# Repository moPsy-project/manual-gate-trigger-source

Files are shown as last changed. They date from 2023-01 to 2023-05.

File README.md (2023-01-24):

# Manual Gate/Trigger Source

> Eurorack Module for a manual gate/trigger source

## Dependencies

This project uses symbols from the [moPsy-KiCad-resources](https://github.com/moPsy-project/moPsy-KiCad-resources).

## License



This work is licensed under a [Creative Commons Attribution-ShareAlike 4.0 International License](http://creativecommons.org/licenses/by-sa/4.0/).

BY: Stefan Haun (mail@tuxathome.de)

See [LICENSE.txt](LICENSE.txt) for details.

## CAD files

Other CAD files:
Frontpanel/manual-gate-outline.FCStd
Frontpanel/manual-gate-outline.dxf

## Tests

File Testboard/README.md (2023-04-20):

# Testboard

> Testboard for the Eurorack Module for a manual gate/trigger source

As described in #53, buttons do not always trigger reliably after a cold start,
i.e. a longer period without power.

This happens on all buttons, but only in the finished circuit. The effect could not be observed on the breadboard and is therefore hard to debug.

This board contains only one trigger and some testpoints.

It is meant to be connected to the [Eurorack Power Breakout](https://github.com/moPsy-project/eurorack-power-breakout).

## Dependencies

This project uses symbols from the [moPsy-KiCad-resources](https://github.com/moPsy-project/moPsy-KiCad-resources).

## License



This work is licensed under a [Creative Commons Attribution-ShareAlike 4.0 International License](http://creativecommons.org/licenses/by-sa/4.0/).

BY: Stefan Haun (mail@tuxathome.de)

See [LICENSE.txt](LICENSE.txt) for details.

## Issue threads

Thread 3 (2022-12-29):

:white_check_mark: Verify stability of op-amp circuits

penguineer, 2022-12-29:
Verify transient behavior with an oscilloscope, at least on the breadboard.

See also https://www.jensen-transformers.com/wp-content/uploads/2014/08/an001.pdf

penguineer, 2023-01-10:
## Setup

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

Simple setup of an TL072 as buffer (unity gain amplifier) and a switch with high pass filter for full voltage swing in a short amount of time.

## Measurement

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

No ringing or resonance could be observed.

Closed 2023-01-10.

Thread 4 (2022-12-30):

:art: Consider alternative voltage generator design

penguineer, 2022-12-30:
The current design using series voltage dividers requires a 3-position selector (SP3T) switch.

Is there a way to implement the resistor divider for voltage generation by using a SPDT switch?
(Such as adding resistors in parallel to shift the voltage.)

(-12V are available, so it might be possible to move 8V to 5V and 10V to honour switch position and natural number order for the voltages.)

This decision can also be influenced by parts availability regarding the switch (#6).

Closed 2023-01-11.

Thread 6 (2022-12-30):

:wrench: Voltage switch selection and footprint

penguineer, 2022-12-30:
Select the appropriate voltage switch (also consider #4) and add the matching footprint.

penguineer, 2023-01-11:
We have decided for an SPDT switch with middle off position (ON/OFF/ON), that can also be replaced by jumper settings.

penguineer, 2023-01-26:
Alternatively this could be a small switch like [SS X23200](http://www.reichelt.de/index.html?ARTICLE=105437) - Schiebeschalter 2x Ein - Ein - Ein

penguineer, 2023-03-09:
When doing Concept 4 of the front panel design, I decided to stick with the decision for a voltage switch.

Closed 2023-03-09.

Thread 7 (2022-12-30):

:wrench: Choose gate length design

penguineer, 2022-12-30:
There are currently two design options for the gate length generator in the schematic:
* LM555 timer
* TL072 op-amp

The op-amp design is untested, but needs fewer components and has the right polarity for the rest of the build (output polarity can be switched easily).

- [x] Test the op-amp design on a breadboard → does not work as desired
- ~~If it works:~~
  - ~~remove 555 design~~
  - ~~change polarity of output~~
- if it does not work:
  - [x]  remove op-amp design
  - ~~change polarity of input~~

penguineer, 2023-01-09:
As discussed in https://github.com/moPsy-project/manual-gate-trigger-source/issues/9#issuecomment-1376312371 the op-amp circuit does not work as desired.

Closed 2023-01-10.

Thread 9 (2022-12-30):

:white_check_mark: Breadboard Experiments

penguineer, 2022-12-30:
Go to the lab (aka [Netz39 Hackerspace](https://www.netz39.de)) and do the following experiments:

- [x] Verify the gate/trigger input is working as intended → https://github.com/moPsy-project/manual-gate-trigger-source/issues/9#issuecomment-1379484607
  - [x] Verify the manual trigger has no bounce effects
  - [x] Verify the gate switch is working as intended
  - [x] Check the signal polarity on the trigger input
  - [x] Check if LPF is needed
  - [x] Fix manual switch circuit → https://github.com/moPsy-project/manual-gate-trigger-source/pull/18
- [x] Verify the op-amp gate length generator → https://github.com/moPsy-project/manual-gate-trigger-source/issues/9#issuecomment-1376312371
  - [x] Verify the circuit is working as intended
  - [x] Check the signal polarity
  - ~~Check if circuit timing is accurate under trigger output load~~
- [x] Verify the 555 gate length generator → https://github.com/moPsy-project/manual-gate-trigger-source/issues/9#issuecomment-1377659194
  - [x] Verify the circuit is working as intended
  - [x] Check the signal polarity
  - [x] Tune the RC values
- [x] Verify the voltage source → https://github.com/moPsy-project/manual-gate-trigger-source/issues/9#issuecomment-1378058845
  - [x] Verify the voltages can be generated and adjusted easily
  - [x] Check output behavior when switching voltages
  - [x] Verify circuit is stable under load
  - [x] Check if LPF is needed
  - [x] Check if feedback capacitor is needed
- [x] Verify gate/trigger output → https://github.com/moPsy-project/manual-gate-trigger-source/issues/9#issuecomment-1379542623
  - [x] Check polarity and verify it matches
  - [x] Verify step behaviour
  - [x] Verify that voltages are output correctly
  - [x] Investigate behavior with changing collector voltages
  - [x] Verify the push-pull behaviour
- ~~Verify transient behavior for power supply filter~~ → Go with the Befaco-inspired design for now. PSU filtering is a bigger topic for another (soon) time.

penguineer, 2023-01-09:
# Verify the op-amp gate length generator

## Setup
The op-amp based pulse generator has been set up on a breadboard with one modification: The timing capacity is set against V- instead if GND to observe polarity, as an electrolytic capacitor was used.

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

It could be verified that the circuit behaves as described.

## Polarity

The specific TL072 used in this experiment could swing up to 1V towards the rails, so the upper output was kept at 11V towards V+ and the lower output was kept at -11V towards V-.

In it's stable state the circuit outputs V+. If the input goes sufficiently below 0V/GND, the output swings towards V- until the set time has run out, then swings back to +V.

In this sense it has a negative polarity.

## Measurement

The circuit has been measured with its output at channel 1 (yellow) and the timing capacitor at channel 2 (cyan).
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

 Overall the behaviour is as expected. Timing is accurate.

Two negative observations:
* There is a slight ringing in the edges (only slightly visible in the shown measurement), which may be due to the fact that this op-amp is not ideal in a comperator setting.
* While the edge is triggered, the output is slightly below its stable value. While this would be compensated by the output circuit, it is not ideal.

It has also been observed that the trigger reacts to the rising edge, i.e. the end of the trigger pulse and is kept at stable level until that pulse has ended.

## Conclusion

While the circuit behaves as described, it's re-trigger behaviour makes it not suitable for the use case.

Since this variant will not be chosen, the accuracy under load has not been measured.

penguineer, 2023-01-10:
# Verify the 555 gate length generator

## Setup

The 555 based generator has been set up on  a breadboard as is.
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

## Polarity and behavior

The monoflop triggers on a falling edge (V+ → GND) and outputs a rising pulse (GND → V+ → GND).
If the trigger is held, the output stays at V+ until the trigger is released or the pulse times out, whichever comes _last_.

## Measurement
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

The output signal (channel 1, yellow) behaves as expected.
Channel 2 (cyan) shows the timing capacitor.

## Conclusion

The circuit is usable with changes to the RC element:
* Change capacitor to 2u2
* Change series resistor to 2k2

penguineer, 2023-01-11:
# Verify the voltage source

## Voltage selection

Voltage selection has been verified in a spice simulation. All voltages could be selected within 80% of the potentiometer range.

penguineer, 2023-01-11:
# Verify the gate/trigger input is working as intended

## Switching Behaviour

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

The leading edge is very sharp and sufficient for our application.

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

The trailing edge is rather slow. However, the change is finished in 50us, which is much shorter than the 1ms minimal gate length.

## Polarity

After a correction in the schematic the input has the desired inverting polarity.

## Conclusion

The circuit works as intended and has the desired switching behaviour.

penguineer, 2023-01-11:
# Verify gate/trigger output

## Setup

The adapted circuit from https://github.com/moPsy-project/manual-gate-trigger-source/pull/16 has been set up on a breadboard:
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

## Switching behavior
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

Switching is sufficiently fast.

Please note that these measurements have been done with BC337/BC227 replacements.

## Conclusion

The push-pull setup is usable.

penguineer, 2023-01-17:
# Final output signal

## Raising edge
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

## Falling edge
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

## Shortest trigger pulse
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

penguineer, 2023-01-17:
#Final Breadboard setup

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

Closed 2023-01-17.

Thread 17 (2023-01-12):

:wrench: Potentiometer selection and footprint

penguineer, 2023-01-12:
Select a fitting potentiometer (1M linear) and find/create a footprint.

penguineer, 2023-01-19:
The following potentiometer has been selected: [Potentiometer - 12mm B1M x5 units](https://shop.befaco.org/potentiometers/279-5x-potentiometer-1m.html)

> 12mm potentiometer with T-18 Knurled shaft. These potentiomters have a 1MΩ linear taper.

Reference: `POTB1M`

Closed 2023-01-25.

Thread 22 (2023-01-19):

:wrench: Gate/Trigger switch selection and footprint

penguineer, 2023-01-19:
Select the appropriate gate/trigger switch and add the matching footprint.

penguineer, 2023-01-19:
Proposition: [Toggle Mini Switch - SPDT ON-ON x5 units](https://shop.befaco.org/switches/265-toggle-mini-switch-spdt-on-on-x5-units.html)

> Miniature SPDT on-on toggle switches with pins for PCB mounting.

References:
* `TSM102A2`
* `SW1`

penguineer, 2023-01-19:
This could also be a push switch to save some space.

penguineer, 2023-01-25:
Another Option: [T 113A BL](http://www.reichelt.de/index.html?ARTICLE=45163) - Miniatur-Drucktaster 0,5A-24VAC, 1x (Ein), bl

As a push-button with state and an indicator LED this might be a better solution.

penguineer, 2023-01-26:
https://www.henrik24.de/de_DE/p/Mikro-Druckschalter-7x7mm-6-Pin-Rastend-Typ/274

Closed 2023-03-08.

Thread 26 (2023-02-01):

:hammer: Redesign voltages for +3V/+5V/+12V

penguineer, 2023-02-01:
According to https://doepfer.de/a100_man/a100t_e.htm, gate voltages should be above 3V, are 5V default and need to be tolerated as 12V.

These should be the voltages we support, which means that #21 is an option for a better voltage supply.

Closed 2023-03-12.

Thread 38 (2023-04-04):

ready to rock?

KeLaiFu, 2023-04-04:
I've been watching you work on this project with great interest and noticed you seem to have stopped the regular updates, does this mean the circuit has reached its final form? I have been toying with the same idea, with less success so I am interested in using your schematic as the base of my euro module.

Really appreciate the stuff you're uploading. thanks!

penguineer, 2023-04-04:
Thank you very much for your nice feedback! :smiley:
You are right, the recent steps in this project didn't leave much of a trace here.

The state of the project:
[The first prototype is done and works.](https://www.patreon.com/posts/first-module-is-80765545) However, while building, I discovered some minor issues with the PCB that need to be worked out.
The circuit itself seems to be working.

So there will be a v1.1 with bugfixes on the PCB.

I am also thinking about a v2 where I drop the voltage switch. This came from a testing environment, but I might solve it differently there and in the performance setup I don't really see as much use for this feature (at least in relation to the effort I made in development and parts to implement this).

penguineer, 2023-04-04:
I am happy to sell you a prototype of v1 for a fair price (covering material and shipping costs), in case you are interested.
As I haven't created build instructions yet, assembling a kit might be a bit of a chore, especially with the current kinks.

Please feel free to get inspiration for your own builds or point out mistakes in my design, :)

penguineer, 2023-04-04:
I am closing this issue and will create new issues with my findings to make it easier to follow up on the progress.

Closed 2023-04-04.

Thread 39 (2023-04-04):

:bug: Fix cutout dimensions in the front panel

penguineer, 2023-04-04:
The front panel cutouts are a bit too tight:
* [x] Height of the cherry switches
* [x] Diameter for the potentiometers

* [x] Diameter for the diodes could also be increased, but works well this way, too.

penguineer, 2023-04-04:
>  Diameter for the potentiometers

After measuring the PCBs: The diameter is correct. It turns out that the cutouts by JLCPCB are smaller than specified.

Closed 2023-04-04.

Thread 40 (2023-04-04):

:bug: Cosmetic issues with v1

penguineer, 2023-04-04:
There are some cosmetic issues with v1:
* [x] The front panel has no solder mask
* [x] URI on the interface panel is mirrored
* [x] Adjustment pots do not state their voltage range

penguineer, 2023-04-04:
> The front panel has no solder mask

This looks interesting, too.

However, I want to figure out
* why the solder mask is missing
* if partial solder mask can be used to improve design and readability

penguineer, 2023-04-04:
>  Adjustment pots do not state their voltage range

I intentionally did not put specific values, as they may be changed by choosing different resistors. But I still want to label with something along the line of "low", "mid", "high".

Closed 2023-04-04.

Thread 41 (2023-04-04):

:bug: High voltage range is too low

penguineer, 2023-04-04:
The pot for the high voltage range barely reaches the target on its upper limit. Resistor values need to be adjusted accordingly.

Closed 2023-05-19.

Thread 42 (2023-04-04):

:bug: 1M potentiometer footprints do not fit

penguineer, 2023-04-04:
After https://github.com/moPsy-project/moPsy-KiCad-resources/issues/13 fix the 1M pot footprints.

Closed 2023-04-04.

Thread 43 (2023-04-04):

:bug: Check the gate switch footprints

penguineer, 2023-04-04:
The gate switch footprints match the [drawing](https://www.henrik24.de/de_DE/p/Mikro-Druckschalter-7x7mm-6-Pin-Rastend-Typ/274#galleryName=productGallery,imageNumber=3), but not the switches which I used during assembly.

Check if there are indeed to varieties of these switches and fix accordingly, either the footprint or the switches.

Closed 2023-05-20.

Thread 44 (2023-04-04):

:lipstick: Replace voltage switch by (trim) potentiometer

penguineer, 2023-04-04:
The voltage switch is overkill in terms of effort (parts and space) to added value.

I want to replace this switch by a (trim) pot that allows to set the trigger output voltage between 4V and 9V (which includes the viable targets of 5V/8V).

This pot can be either on the back or even stick to the front (which has been done with trim pots e.g. in the [Erica Synths Black VCO](https://www.modulargrid.net/e/erica-synths-black-vco)).

penguineer, 2023-05-19:
It is possible to replace the switch while still using the existing frontpanel. Only disadvantage is that the hole is too big.

penguineer, 2023-05-19:
This issue has been fixed in https://github.com/moPsy-project/manual-gate-trigger-source/pull/57/commits/0d254281400b6e1f035b64f6f6d54457fdb192a0

Closed 2023-05-19.

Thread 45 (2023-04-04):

:art: Use 556 instead of 555 to save board space

penguineer, 2023-04-04:
There are four 555 ICs in this build. They can be replaced by two 556 ICs to save on board space and some capacitors.

This requires a review of the sheet hierarchy, tho.

penguineer, 2023-05-19:
This is no longer needed.

Closed 2023-05-19.

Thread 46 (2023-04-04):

:art: Get rid of the Power Board PCB

penguineer, 2023-04-04:
Find a better arrangement of parts to get rid of the additional Power Board PCB.

This will improve the assembly and decrease costs and failure modes.

If possible, this change should be part of [v1.1](https://github.com/moPsy-project/manual-gate-trigger-source/milestone/3https://github.com/moPsy-project/manual-gate-trigger-source/milestone/3), however, if this is not possible, #44 and #45 have to be be resolved first.

Closed 2023-05-19.

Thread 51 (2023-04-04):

:bug: Voltage switch is too high on the board

penguineer, 2023-04-04:
The voltage switch is too high, pushing the front plate 1mm out of alignment.

This can be fixed by creating a footprint that allows the pins to go all the way in, effectively making the switch body sit flat on the PCB.

Closed 2023-04-12.

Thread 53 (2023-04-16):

:bug: Buttons do not always trigger reliably

penguineer, 2023-04-16:
After turning the module on (i.e. switching power on) it sometimes takes a few button pushes to make the buttons trigger reliably. As this is the core function of the module, the behavior is not satisfactory and needs to be improved.

~~The hardware debouncing may be too harsh and is most likely not even used, as the 555 timers make sure that there is a mimimal signal length.~~

penguineer, 2023-04-19:
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

This capacitor is not needed, as the 555 catches any bouncing from the button.

penguineer, 2023-04-21:
Follow-up measurements will be done on a testboard:

[testboard-gerber.zip](https://github.com/moPsy-project/manual-gate-trigger-source/files/11294313/testboard-gerber.zip)

penguineer, 2023-05-17:
The test board has a reliable switch behavior, which makes me think that the actual V_drive generator is the issue.

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

This might be solved with #44 and #46.

penguineer, 2023-05-19:
Closing as I strongly suspect a fix in #57

Closed 2023-05-19.

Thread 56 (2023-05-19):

:art: Change transistor footprints for easier soldering

penguineer, 2023-05-19:
Switch to the TO-92 hand-soldering footprints, as the inline footprints tend to lead to solder bridges.

Closed 2023-05-20.

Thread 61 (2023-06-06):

:bug: Triggering is still unreliable

penguineer, 2023-06-06:
With the changes for v2 and even after the testboard triggering is still unreliable, yet in a more systematic way: The top buttons are less reliable than the bottom ones,leading me to believe that this is a power supply issue.

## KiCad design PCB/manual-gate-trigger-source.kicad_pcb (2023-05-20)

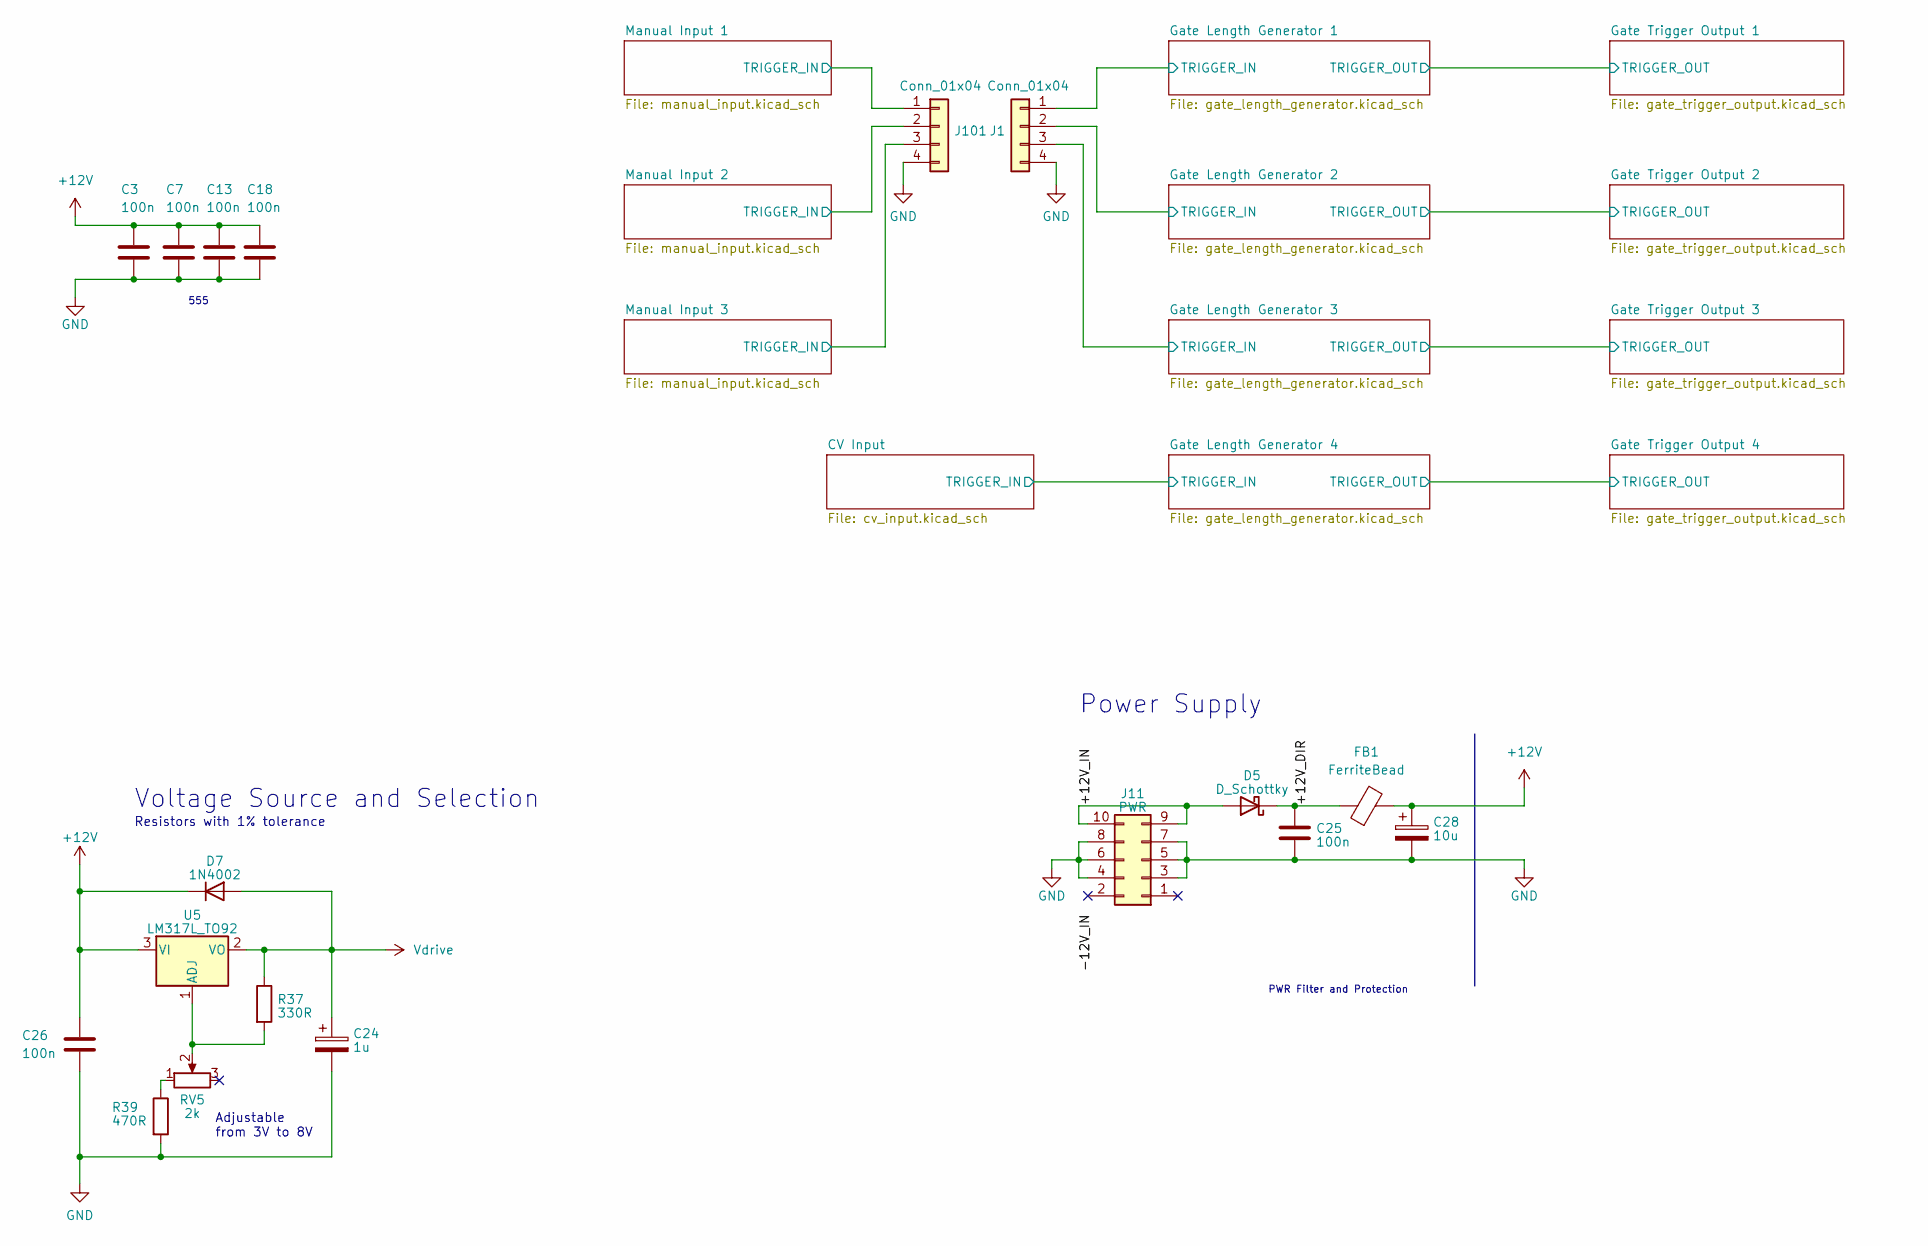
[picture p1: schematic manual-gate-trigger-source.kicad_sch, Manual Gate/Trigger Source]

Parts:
C3, C7, C13, C18, C25, C26: 100n; C_Disc_D4.3mm_W1.9mm_P5.00mm
C24: 1u; CP_Radial_D5.0mm_P2.00mm
C28: 10u; CP_Radial_D4.0mm_P1.50mm
D5: D_Schottky; D_DO-41_SOD81_P7.62mm_Horizontal
D7: 1N4002; D_DO-41_SOD81_P10.16mm_Horizontal
FB1: FerriteBead; FBeadL4D4
J1: Conn_01x04; PinSocket_1x04_P2.54mm_Vertical
J11: PWR; PinHeader_2x05_P2.54mm_Vertical
J101: Conn_01x04; PinHeader_1x04_P2.54mm_Vertical
R37: 330R; R_Axial_DIN0207_L6.3mm_D2.5mm_P7.62mm_Horizontal
R39: 470R; R_Axial_DIN0207_L6.3mm_D2.5mm_P7.62mm_Horizontal
RV5: 2k; Suntan 3296 Trim Pot
U5: LM317L_TO92; TO-92_HandSolder

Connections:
+12V: C3.1, C7.1, C13.1, C18.1, C26.1, C28.1, D7.1 (K), FB1.2, U5.3 (VI); also elsewhere on the board
/+12V_DIR: C25.1, D5.1 (K), FB1.1
/+12V_IN: D5.2 (A), J11.9, J11.10
/Gate Length Generator 1/TRIGGER_IN: J1.1; also elsewhere on the board
/Gate Length Generator 2/TRIGGER_IN: J1.2; also elsewhere on the board
/Gate Length Generator 3/TRIGGER_IN: J1.3; also elsewhere on the board
/Manual Input 1/TRIGGER_IN: J101.1; also elsewhere on the board
/Manual Input 2/TRIGGER_IN: J101.2; also elsewhere on the board
/Manual Input 3/TRIGGER_IN: J101.3; also elsewhere on the board
GND: C3.2, C7.2, C13.2, C18.2, C24.2, C25.2, C26.2, C28.2, J1.4, J11.3, J11.4, J11.5, J11.6, J11.7, J11.8, J101.4, R39.2; also elsewhere on the board
unnamed: R39.1, RV5.1
unnamed: R37.2, RV5.2, U5.1 (ADJ)
Vdrive: C24.1, D7.2 (A), R37.1, U5.2 (VO); also elsewhere on the board

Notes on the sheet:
PWR Filter and Protection
Resistors with 1% tolerance
555
Voltage Source and Selection
Power Supply
Adjustable from 3V to 8V

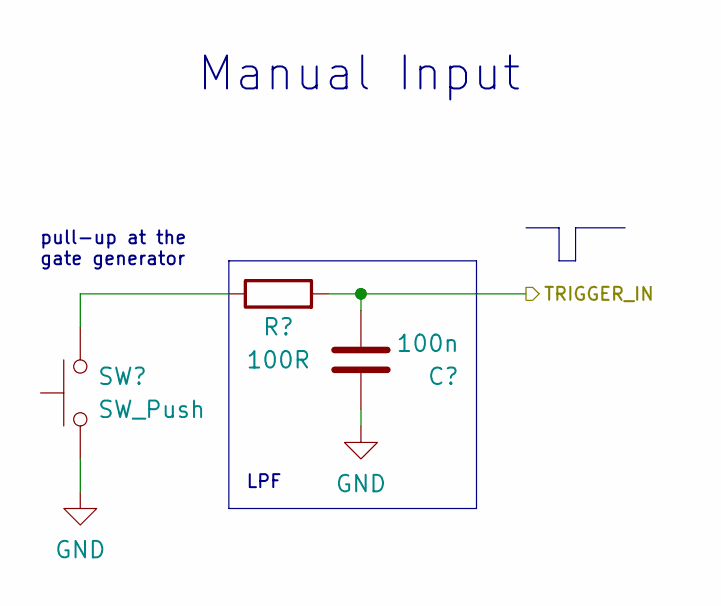
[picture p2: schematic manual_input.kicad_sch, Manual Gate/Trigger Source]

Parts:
C101: 100n; C_Disc_D4.3mm_W1.9mm_P5.00mm
R101: 100R; R_Axial_DIN0207_L6.3mm_D2.5mm_P7.62mm_Horizontal
SW101: SW_Push; SW_Cherry_MX_1.00u_PCB

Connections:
/Manual Input 1/TRIGGER_IN: C101.2, R101.2; also elsewhere on the board
GND: C101.1, SW101.1; also elsewhere on the board
unnamed: R101.1, SW101.2

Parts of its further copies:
C102, C103: 100n; C_Disc_D4.3mm_W1.9mm_P5.00mm
R102, R103: 100R; R_Axial_DIN0207_L6.3mm_D2.5mm_P7.62mm_Horizontal
SW102, SW103: SW_Push; SW_Cherry_MX_1.00u_PCB

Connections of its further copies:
/Manual Input 2/TRIGGER_IN: C102.2, R102.2; also elsewhere on the board
/Manual Input 3/TRIGGER_IN: C103.2, R103.2; also elsewhere on the board
GND: C102.1, C103.1, SW102.1, SW103.1; also elsewhere on the board
unnamed: R102.1, SW102.2
unnamed: R103.1, SW103.2

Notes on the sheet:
pull-up at the gate generator
LPF
Manual Input

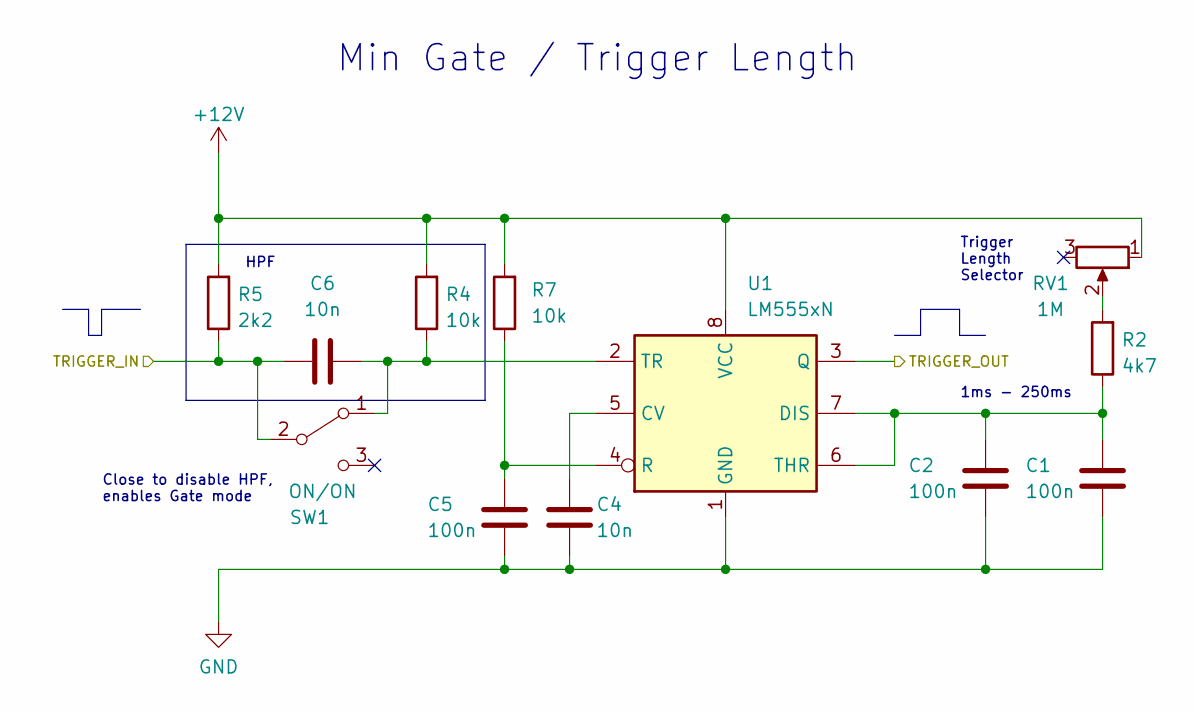
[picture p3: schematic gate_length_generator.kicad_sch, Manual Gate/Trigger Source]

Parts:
C1, C2, C5: 100n; C_Disc_D4.3mm_W1.9mm_P5.00mm
C4, C6: 10n; C_Disc_D4.3mm_W1.9mm_P5.00mm
R2: 4k7; R_Axial_DIN0207_L6.3mm_D2.5mm_P7.62mm_Horizontal
R4, R7: 10k; R_Axial_DIN0207_L6.3mm_D2.5mm_P7.62mm_Horizontal
R5: 2k2; R_Axial_DIN0207_L6.3mm_D2.5mm_P7.62mm_Horizontal
RV1: 1M; Potentiometer_Befaco_12mm_Single_Vertical
SW1: ON/ON; PB_Hor_7x7_2pole_hybrid
U1: LM555xN; DIP-8_W7.62mm

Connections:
+12V: R4.2, R5.2, R7.2, RV1.1, U1.8 (VCC); also elsewhere on the board
/Gate Length Generator 1/TRIGGER_IN: C6.1, R5.1, SW1.2 (B); also elsewhere on the board
/Gate Length Generator 1/TRIGGER_OUT: U1.3 (Q); also elsewhere on the board
GND: C1.2, C2.2, C4.2, C5.2, U1.1 (GND); also elsewhere on the board
unnamed: R2.2, RV1.2
unnamed: C6.2, R4.1, SW1.1 (A), U1.2 (TR)
unnamed: C4.1, U1.5 (CV)
unnamed: C1.1, C2.1, R2.1, U1.6 (THR), U1.7 (DIS)
unnamed: C5.1, R7.1, U1.4 (R)

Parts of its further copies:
C8, C9, C10, C14, C15, C16, C21, C22, C23: 100n; C_Disc_D4.3mm_W1.9mm_P5.00mm
C11, C12, C17, C19, C20, C27: 10n; C_Disc_D4.3mm_W1.9mm_P5.00mm
R10, R15, R25: 4k7; R_Axial_DIN0207_L6.3mm_D2.5mm_P7.62mm_Horizontal
R12, R17, R20, R24, R27, R35: 10k; R_Axial_DIN0207_L6.3mm_D2.5mm_P7.62mm_Horizontal
R18, R28, R36: 2k2; R_Axial_DIN0207_L6.3mm_D2.5mm_P7.62mm_Horizontal
RV2, RV3, RV4: 1M; Potentiometer_Befaco_12mm_Single_Vertical
SW2, SW3, SW4: ON/ON; PB_Hor_7x7_2pole_hybrid
U2, U3, U4: LM555xN; DIP-8_W7.62mm

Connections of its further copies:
+12V: R12.2, R17.2, R18.2, R20.2, R24.2, R27.2, R28.2, R35.2, R36.2, RV2.1, RV3.1, RV4.1, U2.8 (VCC), U3.8 (VCC), U4.8 (VCC); also elsewhere on the board
/CV Input/TRIGGER_IN: C27.1, R36.1, SW4.2 (B); also elsewhere on the board
/Gate Length Generator 2/TRIGGER_IN: C12.1, R18.1, SW2.2 (B); also elsewhere on the board
/Gate Length Generator 2/TRIGGER_OUT: U2.3 (Q); also elsewhere on the board
/Gate Length Generator 3/TRIGGER_IN: C20.1, R28.1, SW3.2 (B); also elsewhere on the board
/Gate Length Generator 3/TRIGGER_OUT: U3.3 (Q); also elsewhere on the board
/Gate Length Generator 4/TRIGGER_OUT: U4.3 (Q); also elsewhere on the board
GND: C8.2, C9.2, C10.2, C11.2, C14.2, C15.2, C16.2, C17.2, C19.2, C21.2, C22.2, C23.2, U2.1 (GND), U3.1 (GND), U4.1 (GND); also elsewhere on the board
unnamed: R10.2, RV2.2
unnamed: R15.2, RV3.2
unnamed: R25.2, RV4.2
unnamed: C12.2, R17.1, SW2.1 (A), U2.2 (TR)
unnamed: C20.2, R24.1, SW3.1 (A), U3.2 (TR)
unnamed: C27.2, R35.1, SW4.1 (A), U4.2 (TR)
unnamed: C11.1, U2.5 (CV)
unnamed: C8.1, C9.1, R10.1, U2.6 (THR), U2.7 (DIS)
unnamed: C10.1, R12.1, U2.4 (R)
unnamed: C17.1, U3.5 (CV)
unnamed: C14.1, C15.1, R15.1, U3.6 (THR), U3.7 (DIS)
unnamed: C16.1, R20.1, U3.4 (R)
unnamed: C19.1, U4.5 (CV)
unnamed: C21.1, C23.1, R25.1, U4.6 (THR), U4.7 (DIS)
unnamed: C22.1, R27.1, U4.4 (R)

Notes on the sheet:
Min Gate / Trigger Length
Trigger Length Selector
HPF
1ms - 250ms
Close to disable HPF, enables Gate mode

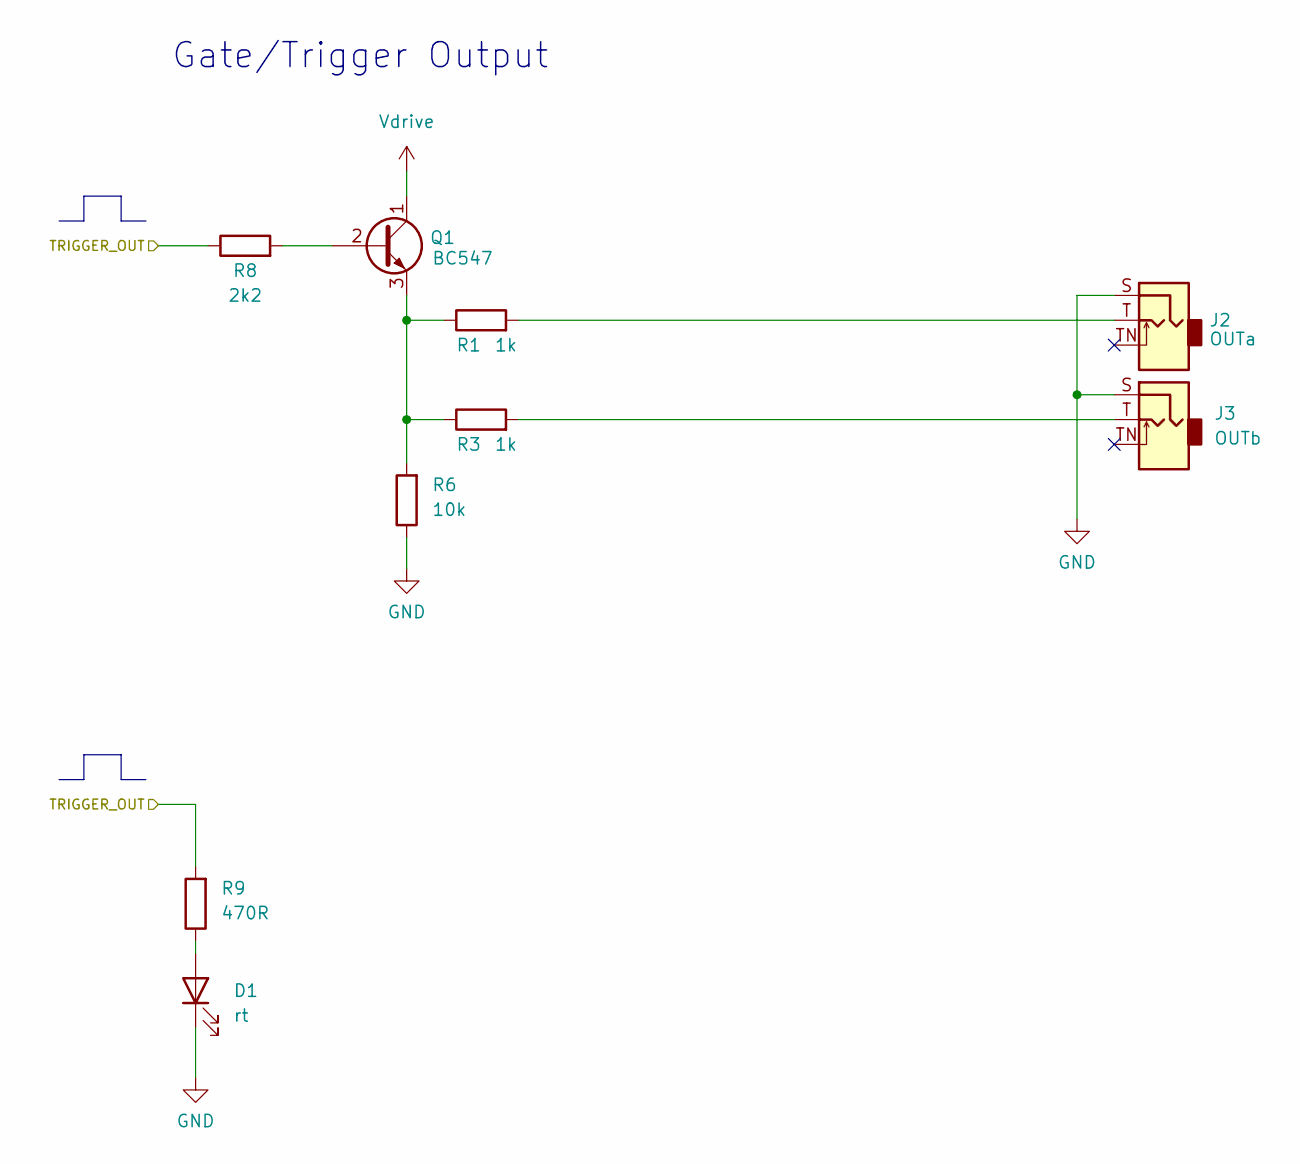
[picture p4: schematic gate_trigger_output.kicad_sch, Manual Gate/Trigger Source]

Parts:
D1: rt; LED_D3.0mm
J2: OUTa; Jack_3.5mm_QingPu_WQP-PJ398SM_Vertical_CircularHoles_Center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
J3: OUTb; Jack_3.5mm_QingPu_WQP-PJ398SM_Vertical_CircularHoles_Center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
Q1: BC547; TO-92_HandSolder
R1, R3: 1k; R_Axial_DIN0207_L6.3mm_D2.5mm_P7.62mm_Horizontal
R6: 10k; R_Axial_DIN0207_L6.3mm_D2.5mm_P7.62mm_Horizontal
R8: 2k2; R_Axial_DIN0207_L6.3mm_D2.5mm_P7.62mm_Horizontal
R9: 470R; R_Axial_DIN0207_L6.3mm_D2.5mm_P7.62mm_Horizontal

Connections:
/Gate Length Generator 1/TRIGGER_OUT: R8.1, R9.2; also elsewhere on the board
GND: D1.1 (K), J2.S, J3.S, R6.1; also elsewhere on the board
unnamed: D1.2 (A), R9.1
unnamed: J2.T, R1.2
unnamed: J3.T, R3.2
unnamed: Q1.2 (B), R8.2
unnamed: Q1.3 (E), R1.1, R3.1, R6.2
Vdrive: Q1.1 (C); also elsewhere on the board

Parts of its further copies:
D2, D3, D6: rt; LED_D3.0mm
J4, J6, J9: OUTa; Jack_3.5mm_QingPu_WQP-PJ398SM_Vertical_CircularHoles_Center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
J5, J7, J10: OUTb; Jack_3.5mm_QingPu_WQP-PJ398SM_Vertical_CircularHoles_Center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
Q2, Q3, Q4: BC547; TO-92_HandSolder
R11, R16, R21, R26, R33, R34: 1k; R_Axial_DIN0207_L6.3mm_D2.5mm_P7.62mm_Horizontal
R13, R23, R30: 2k2; R_Axial_DIN0207_L6.3mm_D2.5mm_P7.62mm_Horizontal
R14, R22, R29: 470R; R_Axial_DIN0207_L6.3mm_D2.5mm_P7.62mm_Horizontal
R19, R32, R38: 10k; R_Axial_DIN0207_L6.3mm_D2.5mm_P7.62mm_Horizontal

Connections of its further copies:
/Gate Length Generator 2/TRIGGER_OUT: R13.1, R14.2; also elsewhere on the board
/Gate Length Generator 3/TRIGGER_OUT: R22.2, R23.1; also elsewhere on the board
/Gate Length Generator 4/TRIGGER_OUT: R29.2, R30.1; also elsewhere on the board
GND: D2.1 (K), D3.1 (K), D6.1 (K), J4.S, J5.S, J6.S, J7.S, J9.S, J10.S, R19.1, R32.1, R38.1; also elsewhere on the board
unnamed: D2.2 (A), R14.1
unnamed: D3.2 (A), R22.1
unnamed: D6.2 (A), R29.1
unnamed: J4.T, R11.2
unnamed: J5.T, R16.2
unnamed: J6.T, R21.2
unnamed: J7.T, R26.2
unnamed: J9.T, R33.2
unnamed: J10.T, R34.2
unnamed: Q2.2 (B), R13.2
unnamed: Q2.3 (E), R11.1, R16.1, R19.2
unnamed: Q3.2 (B), R23.2
unnamed: Q3.3 (E), R21.1, R26.1, R32.2
unnamed: Q4.2 (B), R30.2
unnamed: Q4.3 (E), R33.1, R34.1, R38.2
Vdrive: Q2.1 (C), Q3.1 (C), Q4.1 (C); also elsewhere on the board

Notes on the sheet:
Gate/Trigger Output

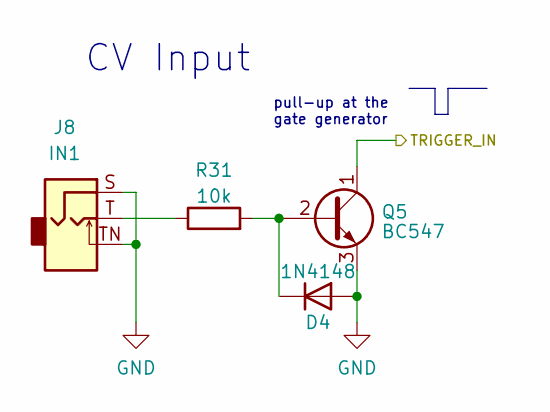
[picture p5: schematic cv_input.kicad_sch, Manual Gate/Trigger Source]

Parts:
D4: 1N4148; D_DO-35_SOD27_P7.62mm_Horizontal
J8: IN1; Jack_3.5mm_QingPu_WQP-PJ398SM_Vertical_CircularHoles_Center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
Q5: BC547; TO-92_HandSolder
R31: 10k; R_Axial_DIN0207_L6.3mm_D2.5mm_P7.62mm_Horizontal

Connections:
/CV Input/TRIGGER_IN: Q5.1 (C); also elsewhere on the board
GND: D4.2 (A), J8.S, J8.TN, Q5.3 (E); also elsewhere on the board
unnamed: D4.1 (K), Q5.2 (B), R31.2
unnamed: J8.T, R31.1

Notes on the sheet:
CV Input
pull-up at the gate generator

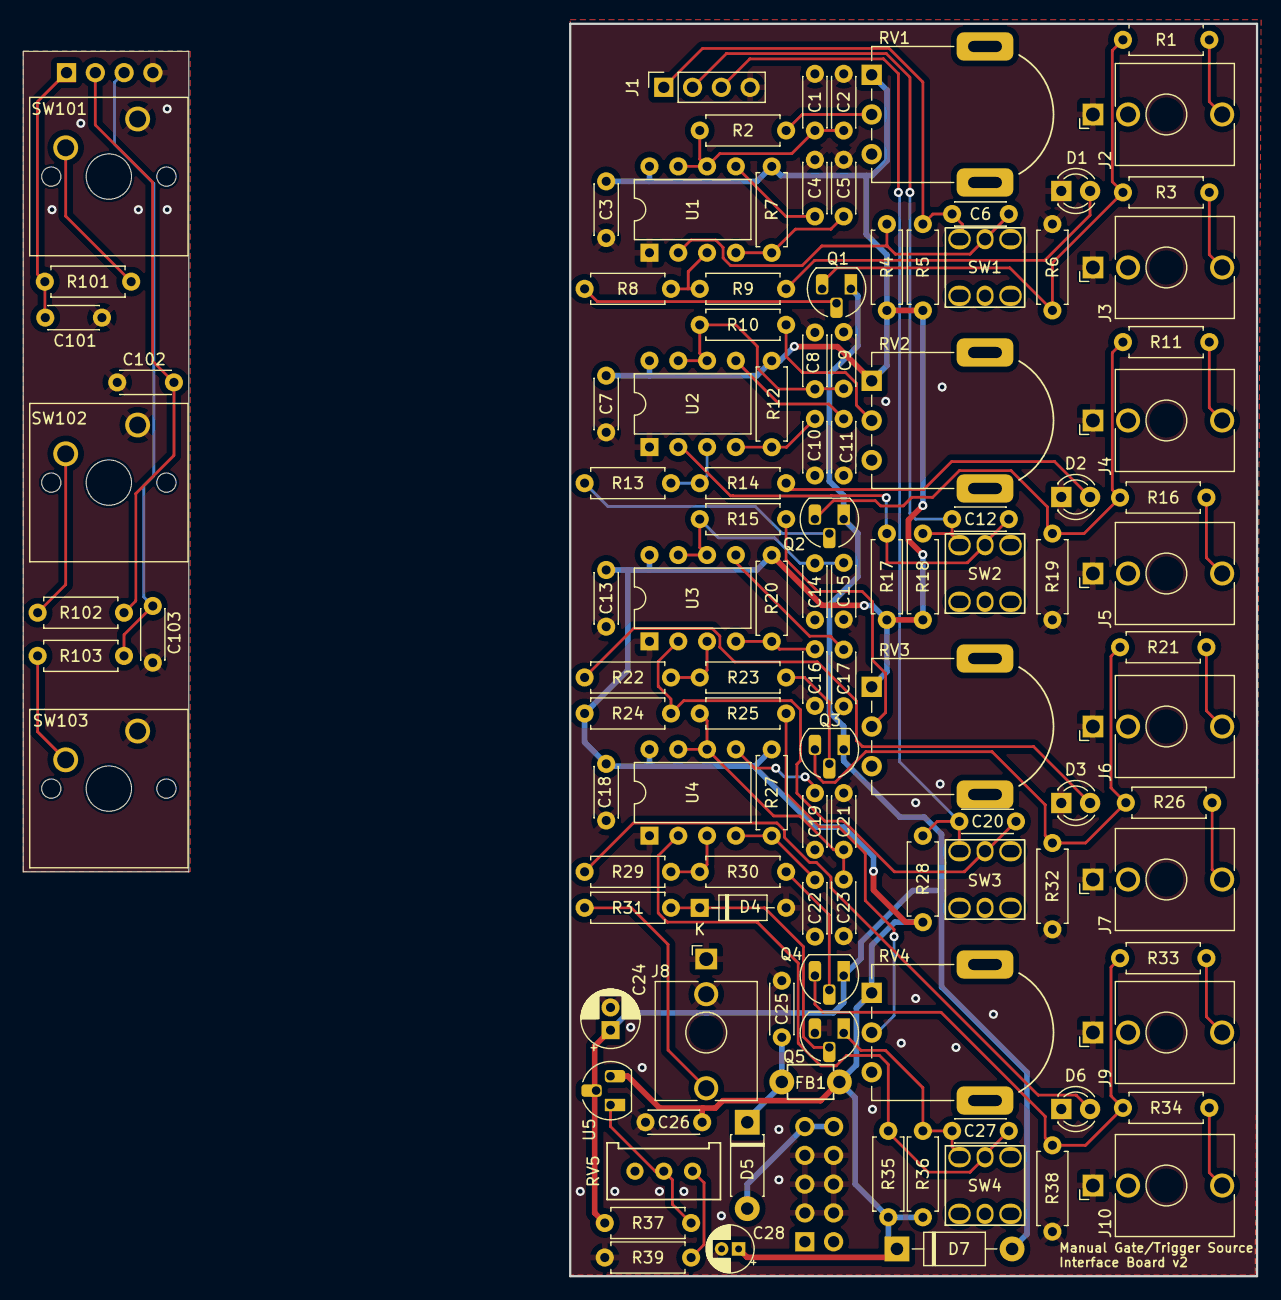
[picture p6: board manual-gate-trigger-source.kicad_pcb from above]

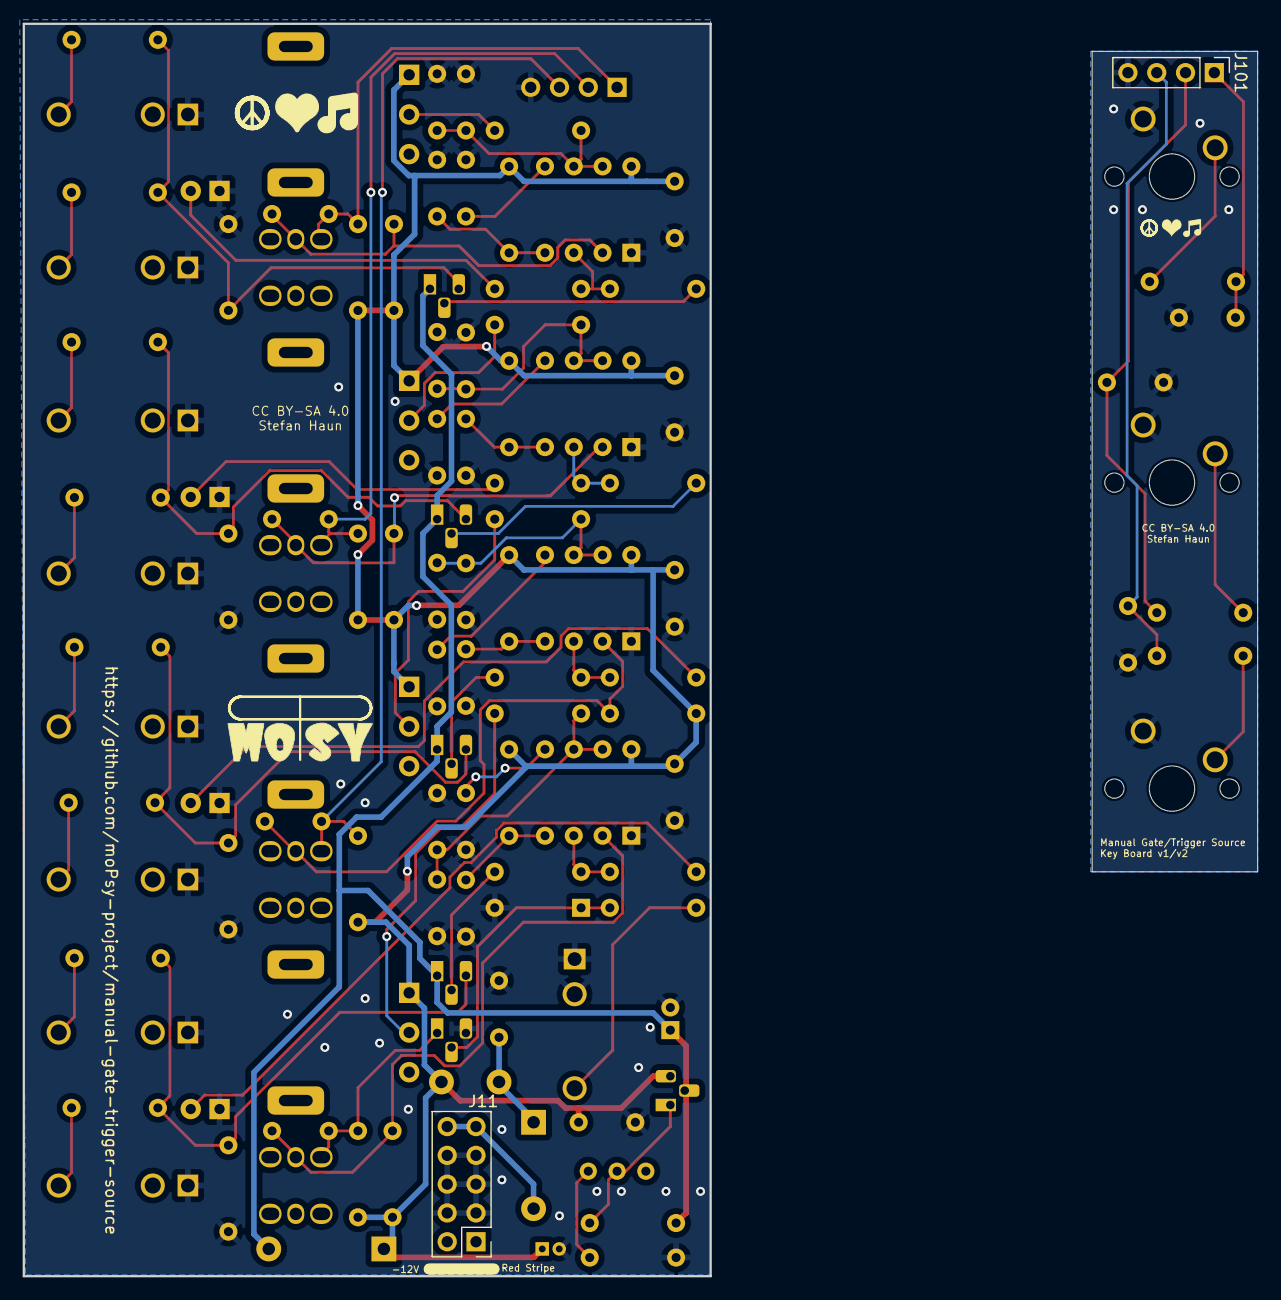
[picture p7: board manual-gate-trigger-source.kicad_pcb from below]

Board: 2 copper layers, 60.6 x 110.5 mm, 115 parts (2 on the bottom side), 63 nets.

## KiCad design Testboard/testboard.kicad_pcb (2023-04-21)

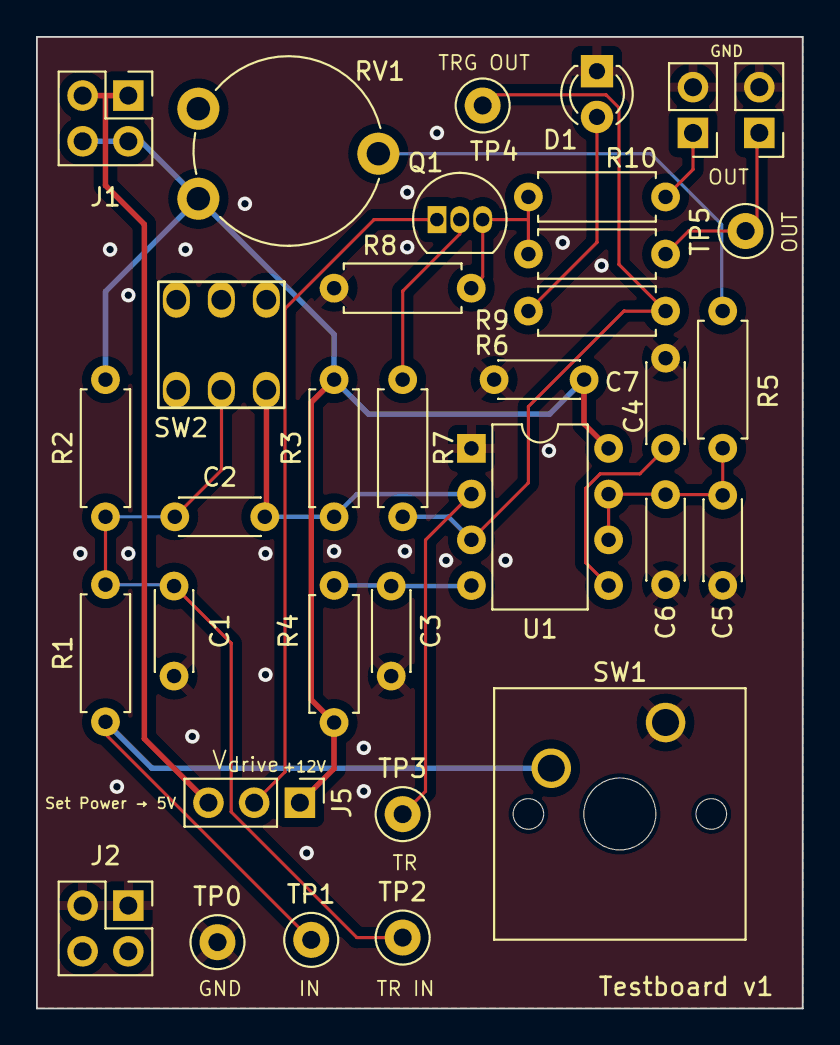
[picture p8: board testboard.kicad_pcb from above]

Board: 2 copper layers, 42.5 x 54.0 mm, 34 parts (0 on the bottom side), 17 nets.

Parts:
C1, C3, C5, C6, C7: 100n; C_Disc_D4.3mm_W1.9mm_P5.00mm
C2, C4: 10n; C_Disc_D4.3mm_W1.9mm_P5.00mm
D1: rt; LED_D3.0mm
J1: upper; PinSocket_2x02_P2.54mm_Vertical
J2: lower; PinSocket_2x02_P2.54mm_Vertical
J3, J4: Out; PinHeader_1x02_P2.54mm_Vertical
J5: V_{drive}; PinHeader_1x03_P2.54mm_Vertical
Q1: BC547; TO-92_Inline
R1: 100R; R_Axial_DIN0207_L6.3mm_D2.5mm_P7.62mm_Horizontal
R2, R7: 2k2; R_Axial_DIN0207_L6.3mm_D2.5mm_P7.62mm_Horizontal
R3, R4, R8: 10k; R_Axial_DIN0207_L6.3mm_D2.5mm_P7.62mm_Horizontal
R5: 4k7; R_Axial_DIN0207_L6.3mm_D2.5mm_P7.62mm_Horizontal
R6: 470R; R_Axial_DIN0207_L6.3mm_D2.5mm_P7.62mm_Horizontal
R9, R10: 1k; R_Axial_DIN0207_L6.3mm_D2.5mm_P7.62mm_Horizontal
RV1: 1M; Potentiometer_Piher_PT-10-V10_Vertical
SW1: SW_Push; SW_Cherry_MX_1.00u_PCB
SW2: ON/ON; PB_Hor_7x7_2pole_2.5mm
TP0: GND; TestPoint_Loop_D1.80mm_Drill1.0mm_Beaded
TP1: IN; TestPoint_Loop_D1.80mm_Drill1.0mm_Beaded
TP2: TRIGGER_IN; TestPoint_Loop_D1.80mm_Drill1.0mm_Beaded
TP3: TR; TestPoint_Loop_D1.80mm_Drill1.0mm_Beaded
TP4: TRIGGER_OUT; TestPoint_Loop_D1.80mm_Drill1.0mm_Beaded
TP5: OUT; TestPoint_Loop_D1.80mm_Drill1.0mm_Beaded
U1: LM555xN; DIP-8_W7.62mm

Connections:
+12V: C7.1, J1.3, J1.4, J5.1, R2.2, R3.2, R4.2, RV1.1, U1.8 (VCC)
/TRIGGER_IN: C1.2, C2.1, R1.2, R2.1, SW2.1 (A), TP2.1
/TRIGGER_OUT: R6.2, R7.1, TP4.1, U1.3 (Q)
GND: C1.1, C3.2, C4.2, C5.2, C6.2, C7.2, D1.1 (K), J2.1, J2.2, J3.2, J4.2, R8.1, SW1.1, TP0.1, U1.1 (GND)
unnamed: D1.2 (A), R6.1
unnamed: J3.1, R9.2, TP5.1
unnamed: J4.1, R10.2
unnamed: J5.2, Q1.1 (C)
unnamed: Q1.2 (B), R7.2
unnamed: Q1.3 (E), R8.2, R9.1, R10.1
unnamed: R1.1, SW1.2, TP1.1
unnamed: R5.2, RV1.2
unnamed: C2.2, R3.1, SW2.2 (B), TP3.1, U1.2 (TR)
unnamed: C4.1, U1.5 (CV)
unnamed: C5.1, C6.1, R5.1, U1.6 (THR), U1.7 (DIS)
unnamed: C3.1, R4.1, U1.4 (R)
Vdrive: J1.1, J1.2, J5.3

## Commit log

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2022-12-17 :tada: Initial kicad project
    [manual-gate-trigger-source.kicad_pcb, manual-gate-trigger-source.kicad_sch]
2022-12-17 :sparkles: Draft a trigger input
    [manual-gate-trigger-source.kicad_sch]
2022-12-28 :sparkles: Draft a trigger output
    Based on http://www.synthpanel.com/modules/cgs24_gatetotrigger.html
    Fixes #1
    [manual-gate-trigger-source.kicad_sch]
2022-12-28 :sparkles: Add OPV-based voltage generation and selector
    [manual-gate-trigger-source.kicad_sch]
2022-12-29 :art: Change voltage generation to R divider
    [manual-gate-trigger-source.kicad_sch]
2022-12-29 :art: Debounce the trigger button
    [manual-gate-trigger-source.kicad_sch]
2022-12-29 :sparkles: Add control for minimum gate and trigger length
    https://www.elektronik-kompendium.de/sites/slt/0310121.htm?mr=100330&mc=10u&mth=2%2C42798
    [manual-gate-trigger-source.kicad_sch]
2022-12-29 :sparkles: Sort out gate/trigger output
    [manual-gate-trigger-source.kicad_sch]
2022-12-29 :sparkles: Set up power supply and filtering
    [manual-gate-trigger-source.kicad_sch]
2022-12-29 :sparkles: Add gate length generator based on op-amp
    On op-amp in the TL072 is unused, so build a gate length generator with this
    which may replace the LM555.
    Based on
    https://circuitdigest.com/electronic-circuits/how-to-design-a-simple-monostable-multivibrator-circuit-using-op-amp
    https://www.electronics-tutorials.ws/de/operationsverstarker/operationsverstaerker-monostabil.html
    [manual-gate-trigger-source.kicad_sch]
2023-01-09 :wrench: Select mono jack and switch symbols
    Chosing PJ398SM (Thonkiconn/Befaco).
    [manual-gate-trigger-source.kicad_sch]
2023-01-10 :pencil2: Fix input polarity of 555 design
    [manual-gate-trigger-source.kicad_sch]
2023-01-10 :hammer: Adjust RC element of 555 gate length generator
    according to
    https://github.com/moPsy-project/manual-gate-trigger-source/issues/9#issuecomment-1377659194
    [manual-gate-trigger-source.kicad_sch]
2023-01-10 :fire: Remove the op-amp design for gate length generator
    [manual-gate-trigger-source.kicad_sch]
2023-01-10 :memo: Remove todo and fix RC annotation
    [manual-gate-trigger-source.kicad_sch]
2023-01-10 :pencil2: Fix HPF for 555 input
    As the signal is one-sided to V+, a second resistor was necessary.
    [manual-gate-trigger-source.kicad_sch]
2023-01-10 :hammer: Move gate/trigger selector to 555 section
    This is very specific to the 555 circuit, so it's better displayed
    there.
    [manual-gate-trigger-source.kicad_sch]
2023-01-11 :art: Improve the voltage selector circuit
    Use parallel resistors to the upper/lower leg of an 8V divider to switch
    between 5V and 10V with a SPDT switch with middle off position
    Fixes: #4
    [manual-gate-trigger-source.kicad_sch]
2023-01-11 :sparkles: Add a drive transistor to the voltage source
    The op-amp alone cannot drive all outputs. Add a transistor as output driver
    and incorporate it into the feedback loop.
    [manual-gate-trigger-source.kicad_sch]
2023-01-11 :wrench: Adjust LPF for then voltage selector switch
    Measurements have shown that this is the best value for the switch that
    will most likely be used.
    [manual-gate-trigger-source.kicad_sch]
2023-01-11 :bug: Fix output ripple by adding a filter cap
    [manual-gate-trigger-source.kicad_sch]
2023-01-11 :bug: Fix missing collector resistor on input transistor
    [manual-gate-trigger-source.kicad_sch]
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2023-01-11 :art: Replace output by push-pull configuration
    [manual-gate-trigger-source.kicad_sch]
2023-01-12 :bug: Fix manual input circuit
    [manual-gate-trigger-source.kicad_sch]
2023-01-12 :wrench: Adjust manual input LPF to match voltage selector
    [manual-gate-trigger-source.kicad_sch]
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2023-01-17 :art: Tune the switch filters
    Tune the switch filters so that no double triggering will
    happen. (Was an issue when releasing the switch.)
    [manual-gate-trigger-source.kicad_sch]
2023-01-17 :hammer: Remove push-pull output
    Push-pull does not perform as expected, go back to the
    tried and tested pull-down resistor, but with a slightly
    lower value. Fall-time is good now.
    [manual-gate-trigger-source.kicad_sch]
2023-01-17 :art: Improve op-amp behavior
    Add a resistor divider and reduce base resistor of the driver
    transistor to improve transient behaviour.
    Also remove the capacitor, as this introduces resonance!
    [manual-gate-trigger-source.kicad_sch]
2023-01-17 :art: Improve output edge speed
    Improve the output speed by reducing the base resistor.
    Changes switching time from 200ns to 50ns.
    [manual-gate-trigger-source.kicad_sch]
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2023-01-19 :sparkles: Duplicate circuit components and complete schmematic
    Multiply input, gate length generator and output
    [manual-gate-trigger-source.kicad_sch]
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2023-01-24 :wrench: Set footprint for voltage selection switch
    Fixes: #6
    [manual-gate-trigger-source.kicad_sch]
2023-01-24 :wrench: Set footprint for gate/trigger switch
    Change the symbol to match the chosen footprint and set the footprint.
    Fixes: #22
    [gate_length_generator.kicad_sch, manual-gate-trigger-source.kicad_sch]
2023-01-25 :wrench: Assign a potentiometer footprint
    Assign footprint for https://shop.befaco.org/potentiometers/279-5x-potentiometer-1m.html
    from the moPsy resources.
    Fixes: #17
    [gate_length_generator.kicad_sch, manual-gate-trigger-source.kicad_sch]
2023-03-08 :hammer: Change voltage switch footprint and move KiCad version
    Unfortunately KiCad did all in one move, so this is a compound commit.
    Fixes #6
    [cv_input.kicad_sch, gate_length_generator.kicad_sch, gate_trigger_output.kicad_sch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]
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2023-03-09 :hammer: Change inputs to the intended 3 manual 1 CV inputs
    There was a mistake when creating the hierarchical sheets leading to 3 CV
    inputs and one manual input instead of the other way around.
    [cv_input.kicad_sch, manual-gate-trigger-source.kicad_sch]
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2023-03-09 :sparkles: Add FreeCAD and DXF for the panel outline
    This outline is based on Concept 4
    [manual-gate-outline.FCStd, manual-gate-outline.dxf]
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2023-03-10 :tada: Add KiCad project for the frontpanel PCB
    [manual-gate-frontpanel.kicad_pcb]
2023-03-10 :sparkles: Implement front panel design based on outline/print
    [manual-gate-frontpanel.kicad_pcb]
2023-03-10 :hammer: Fix SVG for correct rendering in KiCad
2023-03-11 :hammer: Squash panel elements for PCB space
    The top potentiometer was reaching over the PCB outlines and had to be moved
    down. Subsequently the whole designed was quashed together by 3mm to make it
    symmetrical again.
    [manual-gate-outline.FCStd, manual-gate-outline.dxf]
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2023-03-11 :sparkles: Set PCB size and UI component placement
    [cv_input.kicad_sch, gate_trigger_output.kicad_sch, manual-gate-trigger-source.kicad_pcb]
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2023-03-12 :bug: Fix alignment of labels on print
    [manual-gate-frontpanel.kicad_pcb]
2023-03-12 :pencil2: Fix designator placement
    [manual-gate-trigger-source.kicad_pcb]
2023-03-12 :wrench: Adapt resistors to create 3V/5V/8V
    Redesign resistor network for different voltages to fix #26.
    Originally +12V were intended, but this needs extensive changes in the
    schematic, which are not worth the effort here. 8V are provided instead
    to model the usual trigger levels.
    [manual-gate-trigger-source.kicad_sch]
2023-03-13 :bug: Fix a missing connection
    [manual-gate-trigger-source.kicad_pcb]
2023-03-15 :hammer: Remove R6 and R7
    The resistors around the V_drive transistor are not needed with this op-amp
    circuit
    [manual-gate-trigger-source.kicad_sch]
2023-03-15 :hammer: Tie V_drive op-amp to GND instead of -12V
    This op-amp only needs to go down to 3V, so -12V are not needed.
    This was the only device using the negative rail.
    [manual-gate-trigger-source.kicad_sch]
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2023-04-04 :pencil2: Fix switch cutout dimensions
    adding 0.5mm to the height to accomodate the clips.
    [manual-gate-outline.FCStd]
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2023-04-04 :pencil: Decrease LED hole diameter - 3.5mm was too much
    [manual-gate-outline.FCStd]
2023-04-04 :bento: Update DXF export for outline
    [manual-gate-outline.dxf]
2023-04-04 :pencil2: Fix print according to corrected cutouts
2023-04-04 :pencil2: Fix frontpanel PCB according to new print and outline
    [manual-gate-frontpanel.kicad_pcb]
2023-04-04 :pencil2: Fix mirrored URI
    [manual-gate-trigger-source.kicad_pcb]
2023-04-04 :art: Improve positioning and size of some silk screen elements
    [manual-gate-trigger-source.kicad_pcb]
2023-04-04 :art: State voltage range on adjustment pots
    Use "lower", "middle", "upper" instead of actual values, as these might
    be changed during assembly by chosing different resistors.
    [manual-gate-trigger-source.kicad_pcb]
2023-04-04 :pencil2: Adjust to fixed poti footprint
    Adjust to fixed footprint from https://github.com/moPsy-project/moPsy-KiCad-resources/pull/14
    [manual-gate-trigger-source.kicad_pcb]
2023-04-12 :wrench: Change voltage switch footprint to flush version
    This version has been introduced in
    https://github.com/moPsy-project/moPsy-KiCad-resources/pull/16
    for this purpose.
    [manual-gate-trigger-source.kicad_sch]
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2023-04-20 :tada: Add a KiCAD project for the testboard
    [testboard.kicad_pcb, testboard.kicad_sch]
2023-04-20 :sparkles: Create the schematic for the testboard
    Mostly copied from the original schematic.
    [testboard.kicad_sch]
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2023-04-20 :bento: Additional KiCAD project files
2023-04-21 :art: Add a GND testpoint for oscilloscope measurements
    [testboard.kicad_sch]
2023-04-21 :art: Use +5V input as V_drive
    If the pwr breakout is not set correctly, V_drive will be GND, but
    not lead to any issues.
    [testboard.kicad_sch]
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2023-05-19 :hammer: Replace voltage switch by adjustable voltage regulator
    This fixes #41 and #44
    [manual-gate-trigger-source.kicad_sch]
2023-05-19 :hammer: Change PCB layout to match new schematic
    This also fixes #46
    [manual-gate-trigger-source.kicad_pcb]
2023-05-19 :hammer: Change transistor footprints to hand-solder variant
    This fixes #56
    [cv_input.kicad_sch, gate_trigger_output.kicad_sch, manual-gate-trigger-source.kicad_pcb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]
2023-05-20 :hammer: Change switch footprints to hybrid version
    This allows more flexibility when sourcing the switches
    Fixes: #43
    [gate_length_generator.kicad_sch, manual-gate-trigger-source.kicad_pcb]
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

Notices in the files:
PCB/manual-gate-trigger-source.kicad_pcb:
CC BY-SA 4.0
